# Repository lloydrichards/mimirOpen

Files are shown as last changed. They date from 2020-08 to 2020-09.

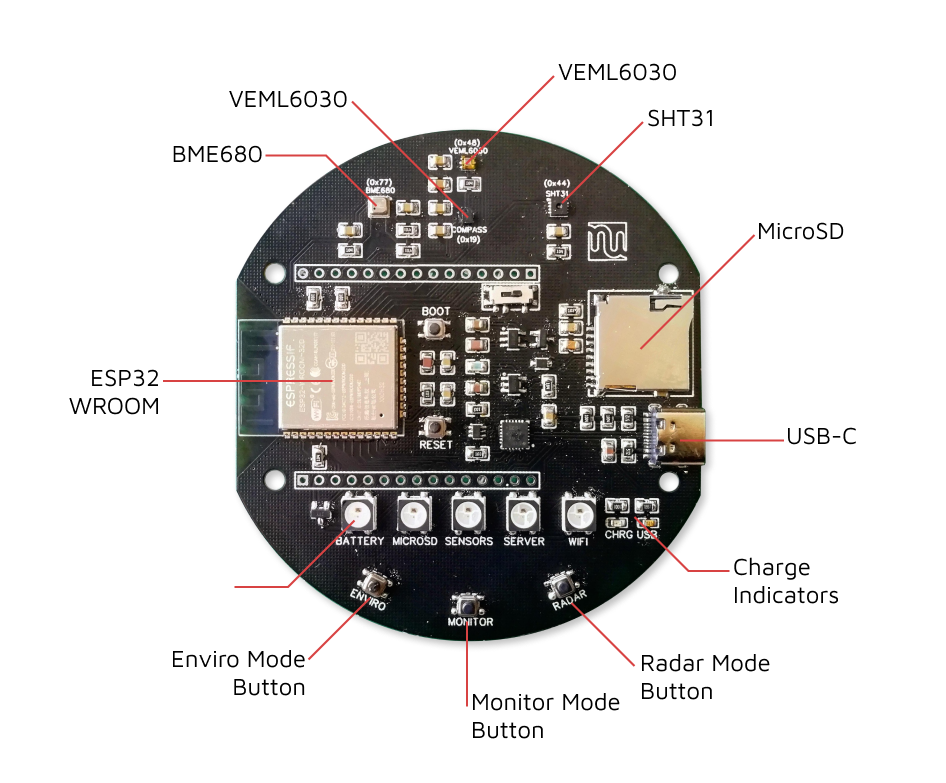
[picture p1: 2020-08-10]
02 Hardware/mimirOpen_V1v0_Labeled.png

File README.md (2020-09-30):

# mimirOpen

Open Hardware project outlining the hardware, software and design schematics for the sensor used by mimirHome.

## Table of Content

1. Design
1. Hardware
1. Software
1. Production
1. Resources

## Version 1.2

With the hardware for the most part all in the right place (except the battery monitor pin), it seems appropriate to move onto the next version. Here we will be optimizing the preformance of the battery and tiding up some of the functions so they're cleaner and more expressive for future adaptation.

In this version I focused on getting the core functionality of booting up the device, initializing systems and then putting the device to sleep. Depending on the bootCount of the device it would sometimes send data to the servers, or have light indications on the system status. Finally, I did some optimization of the timings of the device when it is on and asleep inorder to conserve battery life. As of 9/30 the device turns on for 25-30sec during bootup, sleeps for 5min and then turns on for 2.9sec when just reading and 9.8sec when sending data. This has resulted in the 2000mAh battery lasting a week or two.

## Software with PlatformIO

1. Download or Fork the Repo to your local system.
1. Download Platform IO extension for VS Code
1. Open new window in VS Code, navigate to Platform IO Home
1. Click Projects Tab
1. Click "Add Existing"
1. Find the "03 Software" in the git repo and click "Open '03 Software'"

Now that you're project is setup you should be able to see additional tabs at the bottom of VS Code that will allow you to compile and upload the sketches found in the "src" folder to the device.

_If you open the main.cpp inside /src and VS Code is warning: `cannot open source file "Arduino.h"` then you will need to delete the .vscode folder, close out the window, open a new window and then open the project from Platform IO Home in the Projects tab._

## BUGS

- Brownout on WiFi while on Battery
- Battery Monitoring on wrong Pin
- PNP for turning off LEDs while in deepsleep not working
- Power Switch not on EN of LDO
- Boot Button is redundent

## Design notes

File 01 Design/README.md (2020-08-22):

# mimirOpen - Design
Breaking down the design of the mimirOpen sensor with diagrams, sketches, and notes on some of the decisions or discussions around why it is the what it is.

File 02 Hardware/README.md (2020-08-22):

# mimirOpen - Hardware
Schematics and PCB files for the actual hardware as well as documentation on the sensor choices and testing.

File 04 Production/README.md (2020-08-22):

# mimirOpen - Production
Files and deocumentation what is useful for when you want to actually produce a mimirOpen sensor for yourself.  Included will be bills of materials, quotes and possibly other documentation.

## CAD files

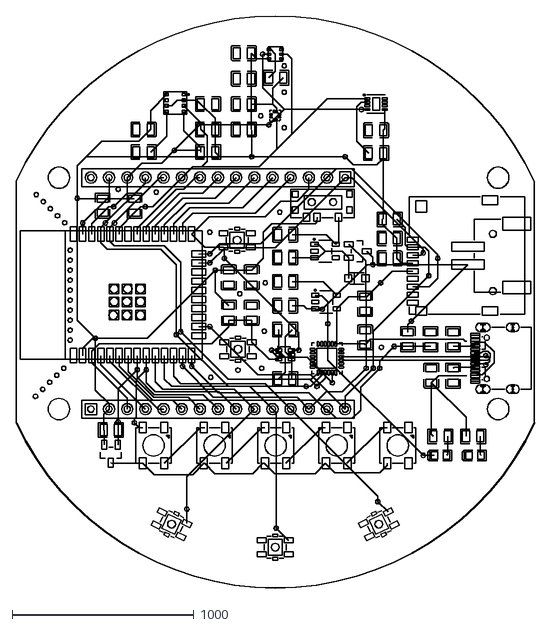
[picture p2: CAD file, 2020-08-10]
02 Hardware/PCB_200910_mimirOpen_V2v0.dxf
2857.5 x 3149.6

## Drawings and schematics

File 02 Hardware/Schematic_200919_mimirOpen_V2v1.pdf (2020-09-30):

## Buttons USB - CHARGE - VCC

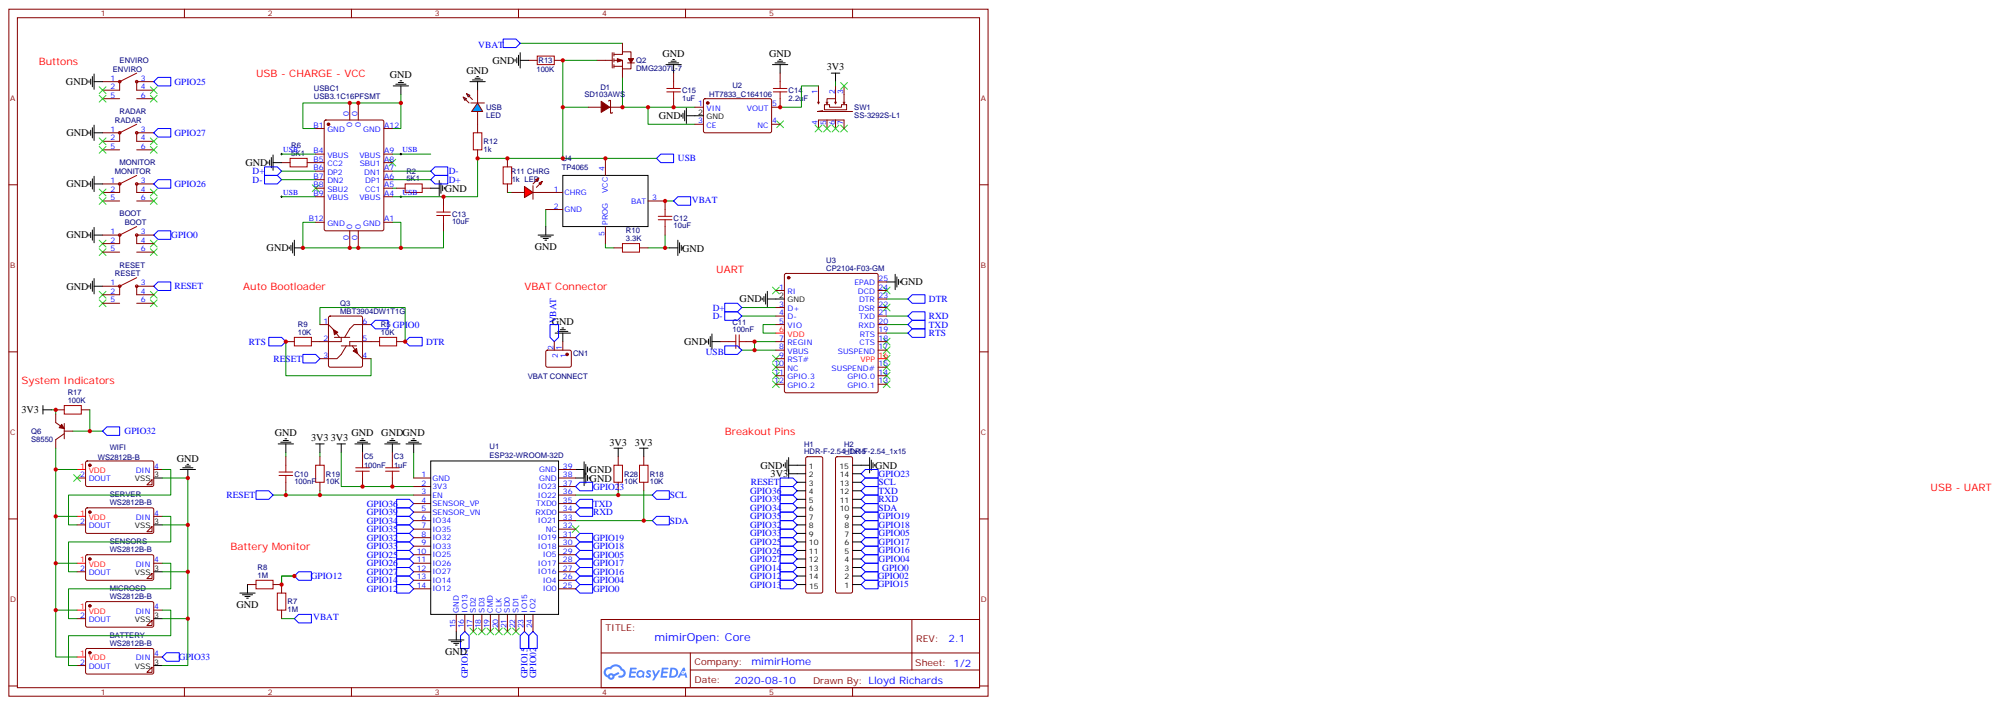
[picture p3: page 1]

Drawn By: Lloyd Richards

## Light Sensors

## Compass

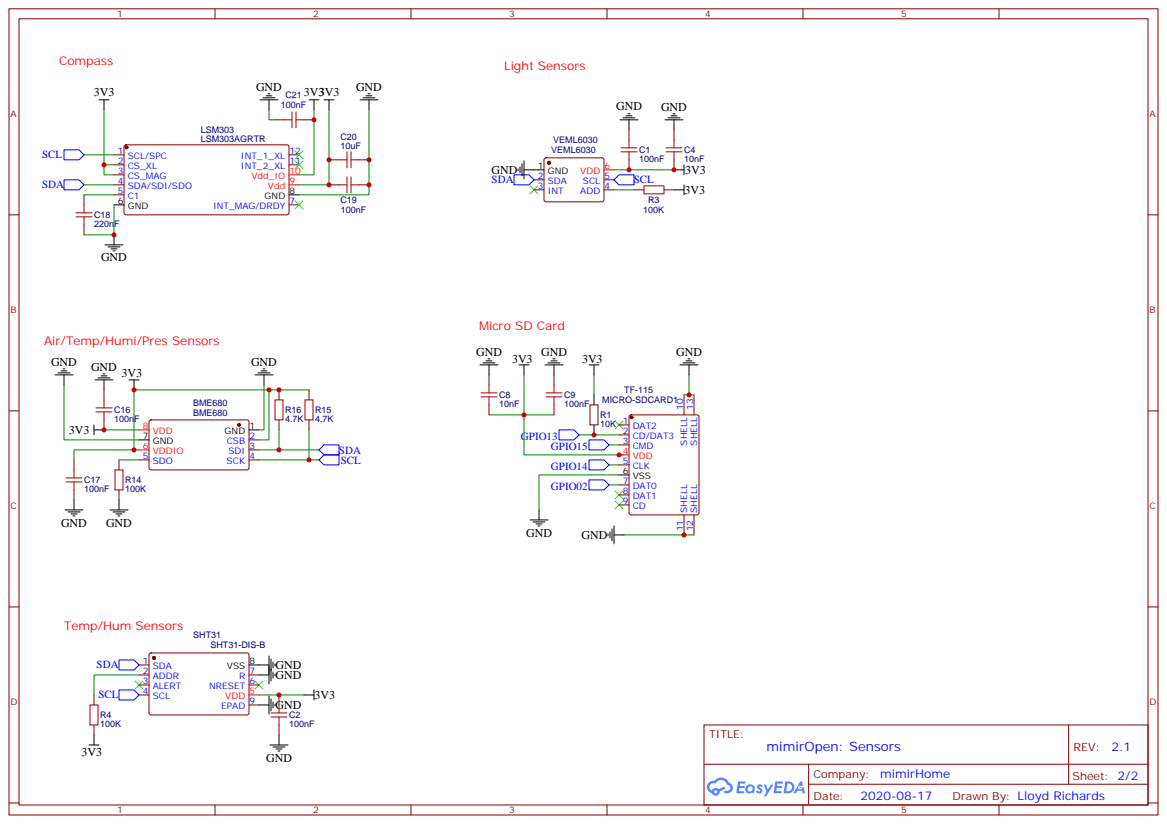
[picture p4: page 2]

Air/Temp/Humi/Pres Sensors
GND

Drawn By: Lloyd Richards

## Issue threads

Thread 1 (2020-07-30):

Missing Resistors on Buttons

lloydrichards, 2020-07-30:
Partly as an oversight on my behave, I left off the 10K resistors on the buttons, assuming that there were internal pull up resistors on the esp32.  While this is true for many of the GPIO, it might not be for the ones the buttons are attached too.

I need to test if this is an issue.

lloydrichards, 2020-08-04:
This was true for the Enviro Button which was on GPIO 34.  Will need to shift everything below 34 to make it work.

lloydrichards, 2020-08-11:
Have changed the pin layout for the buttons to be 25-27 to be able to use to internal pull up resistors.  Button layout is still the same.  See V2.0

Closed 2020-08-11.

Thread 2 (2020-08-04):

LED's on Wrong GPIO Pin

lloydrichards, 2020-08-04:
Have managed to put the LED's on GPIO 36 and 39 which can only be used an inputs.  Will need to change this to something under GPIO34

lloydrichards, 2020-08-12:
Changed to GPIO 32 and 33.  Should fix as outputs now.

Closed 2020-08-12.

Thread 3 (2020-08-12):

Power not coming from battery?

lloydrichards, 2020-08-12:
Booked up a battery and found that no power is coming through the mosfet to the power switch.  Might be cause I've got the sockie on backwards but will need to do some staring at the diagram to make sure I've not done anything silly with the wiring.

lloydrichards, 2020-08-17:
found out I bought the wrong MOSFET for the power switch.  was supposed to get NVTR4503PT1G, not NVTR4503NT1G.  The wiring should be alright so will order new MOSFETS with a few other parts that I'm running low on.

Closed 2020-08-17.

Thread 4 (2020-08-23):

Brownout detection when starting WiFi after deepsleep

lloydrichards, 2020-08-23:
Have noticed that the initial boot programs are running when the device is waking up from deepsleep.  After some digging I noticed the following in the logs:
```rst:0x5 (DEEPSLEEP_RESET),boot:0x13 (SPI_FAST_FLASH_BOOT)
configsip: 0, SPIWP:0xee
clk_drv:0x00,q_drv:0x00,d_drv:0x00,cs0_drv:0x00,hd_drv:0x00,wp_drv:0x00
mode:DIO, clock div:2
load:0x3fff0018,len:4
load:0x3fff001c,len:1044
load:0x40078000,len:8896
load:0x40080400,len:5828
entry 0x400806ac
Wakeup Reason: 4
mounted file system
reading config file
opened config file

parsed json
{"email":"tester@word.com","serialNumber":"test","deviceName":"Test","userId":"ztx11HwFoJPuDJd1p7lLilvvkjg2","deviceId":"SAGvj9Ar25aG4i3Xxta1"}Initializing SD card...
File already exists
SHT31 Success!
VEML6030 Success!
BME680 Success!
Compass Success!
Temp: 26.24
Humi: 40.96
Pres: 97136.00
Alt: 354.75
Lux: 936.00
IAQ: 25.00
eVOC: 0.50
eCO2: 500.00
Bearing: 83
Saving dataAppending to file: /testing.txt
Message appended
*WM:
*WM: AutoConnect
*WM: Connecting as wifi client...
*WM: Using last saved values, should be faster

Brownout detector was triggered

ets Jun  8 2016 00:22:57

rst:0xc (SW_CPU_RESET),boot:0x13 (SPI_FAST_FLASH_BOOT)
configsip: 0, SPIWP:0xee
clk_drv:0x00,q_drv:0x00,d_drv:0x00,cs0_drv:0x00,hd_drv:0x00,wp_drv:0x00
mode:DIO, clock div:2
load:0x3fff0018,len:4
load:0x3fff001c,len:1044
load:0x40078000,len:8896
load:0x40080400,len:5828
entry 0x400806ac
```

So it seems that there is a voltage loss when going into wifi mode so quickly.  Will try a different USB C cable and it on the battery when I get the new MOSFET.  Otherwise, I might need to change some of the capacitors to increase its stability after being asleep.

lloydrichards, 2020-09-22:
After adding back Brownout detection, I'm not getting the same error.  Maybe there was a bad solder with the board I was testing?  I'll still get the other LDOs next part run just to test, but maybe the issue wasn't the LDO

Closed 2020-11-11.

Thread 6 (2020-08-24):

NPN Switch on NeoPixels

lloydrichards, 2020-08-24:
Managed to mix up some NPN transistors for the PNP ones I need 😢 Will need to get the right part to test if the switch works correctly, but for now, I've bridged the connection with a 0-ohm resistor and got the examples working correctly.

lloydrichards, 2020-09-19:
I think I've got a working hack for the battery monitor.  Have cut the Pin12 line and bridged the pinout for 12 and 34.  Needed the change the code a bit so it actually gets the right voltage

`volt = (read * 3.3 / 4096) * 1.115`

Have set it up to take readings and see I can see a decrease in the battery over time.  If successful, will hack the other versions I have and update the schematics for V2.2

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

Closed 2020-11-11.

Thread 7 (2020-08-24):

Resistance on Battery Sensor too high

lloydrichards, 2020-08-24:
After implementing the code on the battery monitor, I realized that I was using two 1M resistors which exceed the internal impedance of the ESP32.  have switched them out for 100K and will retest.  If this works then will change the schematic

lloydrichards, 2020-09-19:
This also seems to be working when reducing the resistance, though at the same time having the pin wrong wasn't helping.  Will update this to V2.2

Closed 2020-09-19.

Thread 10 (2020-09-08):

Battery Monitor on Wrong Pin

lloydrichards, 2020-09-08:
Was wondering why I wasn't getting any readings on the Battery Monitor.  Realized that I had it strapped to Pin 12 which is one of the bootstrap pins and has a 51K resistor on it.  Will need to change this to another pin, most likely GPIO34 on the next version.  There is a chance I could hack together something to test this, but for now, it definitely won't work on GPIO12

Closed 2020-11-11.

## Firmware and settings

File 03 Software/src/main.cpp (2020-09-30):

// NeoPixelTest
// This example will cycle between showing four pixels as Red, Green, Blue, White
// and then showing those pixels as Black.
//
// Included but commented out are examples of configuring a NeoPixelBus for
// different color order including an extra white channel, different data speeds, and
// for Esp8266 different methods to send the data.
// NOTE: You will need to make sure to pick the one for your platform
//
//
// There is serial output of the current state so you can confirm and follow along
//
#include <Arduino.h>
#include "mimirOpen.h"
#include "soc/soc.h"
#include "soc/rtc_cntl_reg.h"
#include <bsec.h>
#include <NeoPixelBus.h>

mimirOpen mimir(115200);
DataPackage sendData;
AuthPackage sendAuth;

RgbColor RED(128, 0, 0);
RgbColor YELLOW(64, 64, 0);
RgbColor GREEN(0, 128, 0);

RTC_DATA_ATTR int bootCount = 0;
RTC_DATA_ATTR uint8_t BSECState[BSEC_MAX_STATE_BLOB_SIZE] = {0};
RTC_DATA_ATTR int64_t BSECTime = 0;

void setup()
{
    ///////////////////////////////////////////////////
    //////////////////////STARTUP//////////////////////
    ///////////////////////////////////////////////////
    esp_sleep_wakeup_cause_t wakeup_reason = esp_sleep_get_wakeup_cause();
    // int wakeUpGPIONumber = int(log(esp_sleep_get_ext1_wakeup_status()) / log(2));
    // switch (wakeUpGPIONumber)
    // {
    // case ENVIRO_PIN:
    //     Serial.println("ENVIRO Button Pushed!");
    //     return;
    // case MONITOR_PIN:
    //     Serial.println("MONITOR Button Pushed!");
    //     return;
    // case RADAR_PIN:
    //     Serial.println("RADAR Button Pushed!");
    //     return;
    // default:
    //     mimir.printBootReason();
    //     return;
    // }
    int BatPercent = mimir.getBatteryPercent(mimir.getBatteryVoltage());
    Serial.print("Battery Percent: ");
    Serial.print(BatPercent);
    Serial.println("%");
    config config = mimir.initSPIFFS();
    mimir.initPixels();
    if (bootCount == 0)
    {
        mimir.pixelBootUp();
        mimir.pixelSystemStatus(BATTERY, RgbColor(map(BatPercent, 0, 100, 128, 0), map(BatPercent, 0, 100, 0, 128), 0));
        mimir.pixelSystemStatus(MICROSD, YELLOW);
        mimir.initMicroSD("/testing.txt") ? mimir.pixelSystemStatus(MICROSD, GREEN) : mimir.pixelSystemStatus(MICROSD, RED);
        mimir.pixelSystemStatus(SENSORS, YELLOW);
        mimir.initSensors(BSECState, BSECTime) ? mimir.pixelSystemStatus(SENSORS, GREEN) : mimir.pixelSystemStatus(SENSORS, RED);
    }
    else
    {
        mimir.initMicroSD("/testing.txt");
        mimir.initSensors(BSECState, BSECTime);
    }

    envData data = mimir.readSensors(BSECState, BSECTime);
    mimir.printSensors(data);

    ///////////////////////////////////////////////////
    /////////////////////MODE CHANGE///////////////////
    ///////////////////////////////////////////////////
    if (wakeup_reason == ESP_SLEEP_WAKEUP_EXT0)
    {
        Serial.println("\nMonitor Button was pressed!");
        mimir.changeMode(&config, 8000);
    }

    ///////////////////////////////////////////////////
    /////////////////////FORCED MODE///////////////////
    ///////////////////////////////////////////////////
    if (digitalRead(ENVIRO_PIN) == LOW && digitalRead(RADAR_PIN) == LOW)
    {
        Serial.println("\nEntering Forced Mode");
        mimir.forceWIFI(&config);
    }

    ///////////////////////////////////////////////////
    ///////////////////////ON BOOT/////////////////////
    ///////////////////////////////////////////////////
    if (bootCount == 0)
    {
        mimir.pixelSystemStatus(WIFI, YELLOW);
        mimir.initWIFI(&config) ? mimir.pixelSystemStatus(WIFI, GREEN) : mimir.pixelSystemStatus(WIFI, RED);

        sendData.auth.deviceId = config.deviceId;
        sendData.auth.userId = config.userId;
        sendData.auth.serialNumber = config.serialNumber;
        sendData.auth.macAddress = WiFi.macAddress();
        sendData.status = mimir.getStatus();
        sendData.data = data;

        sendAuth.email = config.email;
        sendAuth.serialNumber = config.serialNumber;
        sendAuth.macAddress = WiFi.macAddress();

        mimir.logData(data, "/testing.txt");

        mimir.WiFi_ON();
        mimir.pixelSystemStatus(SERVER, YELLOW);
        if (mimir.sendAuth("https://us-central1-mimirhome-app.cloudfunctions.net/dataTransfer/auth", sendAuth, &config))
        {
            mimir.pixelSystemStatus(SERVER, GREEN);
            mimir.sendData("https://us-central1-mimirhome-app.cloudfunctions.net/dataTransfer/add", sendData, &config);
        }
        else
        {
            mimir.pixelSystemStatus(SERVER, RED);
        }
        mimir.WiFi_OFF();
    }
    ///////////////////////////////////////////////////
    //////////////////////SEND DATA////////////////////
    ///////////////////////////////////////////////////
    if (bootCount % 3 == 0 && bootCount != 0)
    {
        sendData.auth.deviceId = config.deviceId;
        sendData.auth.userId = config.userId;
        sendData.auth.serialNumber = config.serialNumber;
        sendData.auth.macAddress = WiFi.macAddress();
        sendData.status = mimir.getStatus();
        sendData.data = data;
        mimir.logData(data, "/testing.txt");
        //Everything that happens with the server happens in here
        WRITE_PERI_REG(RTC_CNTL_BROWN_OUT_REG, 0); //disable brownout detector
        delay(500);
        mimir.WiFi_ON();
        mimir.sendData("https://us-central1-mimirhome-app.cloudfunctions.net/dataTransfer/add", sendData, &config);
        mimir.WiFi_OFF();
        WRITE_PERI_REG(RTC_CNTL_BROWN_OUT_REG, 1); //enable brownout detector
    }
    ///////////////////////////////////////////////////
    /////////////////////SLEEP TIME////////////////////
    ///////////////////////////////////////////////////

    mimir.saveToSPIFFS(config);
    Serial.println("\n-----------------");
    Serial.print("Boot Count: ");
    Serial.println(bootCount);
    bootCount++;
    mimir.SLEEP(5);
}

void loop(){};

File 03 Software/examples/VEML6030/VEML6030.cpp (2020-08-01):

/*
  This example code will walk you through how to enable power save mode on your
  Ambient Light Sensor. When would you use power save mode? The datasheet
  specifies that power save mode is perfect when you want to continuously
  sample ambient light readings from your sensor, as opposed to getting a
  reading once an hour for example. The benefit of power save mode is lower
  power consumption, with current draw in the single digit micro-amp range. 
  Enabling the power save mode decreases the refresh rate of the sensor and so
  sampling should happen at a slower rate. Last thing, the refresh rate is also
  dependent on the integration time setting of the sensor. See the hookup guide 
  for a table showing the correlation of refresh times, current consumption, power 
  mode, and integration mode settings. 

  SparkFun Electronics
  Author: Elias Santistevan
  Date: July 2019

	License: This code is public domain but if you use this and we meet someday, get me a beer! 

	Feel like supporting our work? Buy a board from Sparkfun!
	https://www.sparkfun.com/products/15436

*/

#include <Wire.h>
#include "SparkFun_VEML6030_Ambient_Light_Sensor.h"

// Close the jumper on the product to use address 0x10.
#define AL_ADDR 0x48

SparkFun_Ambient_Light light(AL_ADDR);

// Possible values: .125, .25, 1, 2
// Both .125 and .25 should be used in most cases except darker rooms.
// A gain of 2 should only be used if the sensor will be covered by a dark
// glass.
float gain = .125;

// Possible integration times in milliseconds: 800, 400, 200, 100, 50, 25
// Higher times give higher resolutions and should be used in darker light. 
int _time = 400;
long luxVal = 0; 

// Power save mode, options range from 1-4. 
// Default is 1.
int powMode = 2; 

void setup(){

  Wire.begin();
  Serial.begin(115200);

  if(light.begin())
    Serial.println("Ready to sense some light!"); 
  else
    Serial.println("Could not communicate with the sensor!");

  // Again the gain and integration times determine the resolution of the lux
  // value, and give different ranges of possible light readings. Check out
  // hoookup guide for more info. 
  light.setGain(gain);
  light.setIntegTime(_time);

  Serial.println("Reading settings..."); 
  Serial.print("Gain: ");
  float gainVal = light.readGain();
  Serial.print(gainVal, 3); 
  Serial.print(" Integration Time: ");
  int timeVal = light.readIntegTime();
  Serial.println(timeVal);

  // Power save mode enables low power consumption from your Ambient Light
  // Sensor. You can set modes from 1-4, four being the highest power saving
  // option but slowest refresh rate. The sensor's refresh rate is also
  // dependent on the integration time. For example a setting of 4 with an
  // integration time of 100ms == 4100ms refresh rate but 2 micro-amps current
  // draw. Check hookup guide for more info. 
  light.setPowSavMode(powMode);
  // Let's see that it was set correctly. 
  Serial.print("Power Save Mode: "); 
  int savVal = light.readPowSavMode();
  Serial.println(savVal);
  light.enablePowSave();
  Serial.println("Is power save enabled: ");
  int enaVal = light.readPowSavEnabled(); 

  if(enaVal)
    Serial.println("Yes!");
  else
    Serial.println("No!");  

  // This will power down the sensor and the sensor will draw 0.5 micro-amps of
  // power while shutdown. 
  // light.shutDown();
  // light.powerOn();

  // Give some time to read your settings. 
  delay(1000);

}

void loop(){

  luxVal = light.readLight();
  Serial.print("Ambient Light Reading: ");
  Serial.print(luxVal);
  Serial.println(" Lux");  
  // Sampling at the rate specified in the hookup guide power save mode table. 
  delay(2400);

}

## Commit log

2020-08-05 feat: Updated config to SPIFFS
    Changed how the information is saved and retreived from SPIFFS on config. Will need to add how the device goes into sleep mode depending on this config too
2020-08-06 feat: Fixed Sleep and intervals
    Reworked the sleep functions and set up the package data to be able to send informationt to the servers. Will need to build the backend for it now.
    [main.cpp]
2020-08-10 content: Hardware Schematics
    [PCB_200910_mimirOpen_V2v0.dxf]
2020-08-23 fix: Brownout Bug
    There was a problem with the device having a drop in voltage when starting the wifi after deepsleep. Have turned off the brownout detection for the time it sends the data to fix this, but will need to do some hardware changes too
    [main.cpp]
2020-08-24 feat: Accel, Buttons and Lights
    Got the new boards in so testing out the features that were broken in the last version. Appart from an issue with the NPN not being a PNP, Everything seems to be working correctly
    [Accel.cpp, Compass.cpp, pixelFunLoop.cpp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]
2020-08-24 feat: Battery Monitoring
    Have added back in the code to measure the battery voltage and percent and send this with the rest of the data to the server
2020-08-24 feat: Wake Up Pin
    Added a wakeup pin on the monitor button as well as implimented some basic pixel lights when its starts up or sends data.
2020-08-26 feat: Change Mode
    Implimented a waiting state when the device is awoken by by monitor press. Also tried again to impliment the BME680 in deep sleep but so far unsuccessful
2020-08-27 fix: BME680 works with DeepSleep
    [main.cpp]
2020-09-12 fix: Serial Number getting Cut Shoty
2020-09-19 update: Schematic to 2.1
2020-09-19 feat: Changed Battery Monitor
2020-09-22 feat: Tweaked Power Settings
2020-09-29 feat: Multiple Button WakeUp
2020-09-29 feat: Decreased Board CPU Speed
2020-09-30 feat: Bootup LED Indicators
